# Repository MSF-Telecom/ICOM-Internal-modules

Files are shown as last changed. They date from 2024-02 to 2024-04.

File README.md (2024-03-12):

# ICOM Internal modules

A collection of custom internal modules for ICOM IC-F5060/6060 radios.

## Pinouts

The IC-F5060/6060 and IC-F3162T radios have two 40-pin accessory connectors (J1 and J2). They mate with a [Panasonic P5 Series P5K AXK640347YG](https://na.industrial.panasonic.com/products/connectors/board-board-connectors/lineup/narrow-fine-pitch-connectors/series/82696/model/83045) connector.  
You can find a KiCAD Library for J1 and J2 to make your own modules [here](./CAD-Libs/ICOM-J1-J2). The pinouts are as follows (from the service manual) :

### J1

```ascii
           ┌─────╮
      NC   │40  1│   NC
     GND   │39  2│   GND
     +5V   │38  3│   PTTI
     VCC   │37  4│   PTTO
      NC   │36  5│   MCOT
   MMUTI   │35  6│   NC
    AFON   │34  7│   MCIN
    BEPO   │33  8│   NC
    RMUT   │32  9│   NC
    DISC   │31 10│   NC
   AFOUT   │30 11│   NC
      NC   │29 12│   BUSY
     REM   │28 13│   SIGO
     CCS   │27 14│   OPT1/RxD
    CIRQ   │26 15│   OPT2/TxD
      NC   │25 16│   OPT3
     CSO   │24 17│   GND
     CSI   │23 18│   OPV3
     CCK   │22 19│   OPV2
      NC   │21 20│   OPV1
           └─────╯
```

### J2

```ascii
           ┌─────╮
     DIF   │40  1│   DIF
     GND   │39  2│   GND
     +5V   │38  3│   NC
      8V   │37  4│   NC
      NC   │36  5│   NC
      NC   │35  6│   DMO
      NC   │34  7│   NC
      NC   │33  8│   DMI
      NC   │32  9│   NC
    DISC   │31 10│   VREF
      NC   │30 11│   NC
    DAFO   │29 12│   NC
      NC   │28 13│   NC
     CCS   │27 14│   OPT1 (DPDN)
    CIRQ   │26 15│   OPT2 (DRES)
      NC   │25 16│   OPT3 (DRES)
     CSO   │24 17│   GND
     CSI   │23 18│   NC
     CCK   │22 19│   GND
     GND   │21 20│   GND
           └─────╯
```

## Acknowledgements

Made with ❤️, lots of ☕️, and lack of 🛌  
Published under CreativeCommons BY-SA 4.0

  
This work is licensed under a [Creative Commons Attribution-ShareAlike 4.0 International License](http://creativecommons.org/licenses/by-sa/4.0/).

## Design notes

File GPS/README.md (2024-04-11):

# GPS Module

All the files and R&D data for a custom GPS module.

## Module Design Specifications

A.  Must have  

  1. UT-126H form factor (20x35mm)
  2. UART NMEA GPS module with 4800/9600 baud rate
  3. 5V Supply compatible
  4. 5V Antenna supply
  5. UFL Antenna connector
  6. Test pads for VCC, GND, TX, RX and PPS

B.  Nice to have

  1. Switchable antenna supply
  2. Backup battery circuitry
  3. Antenna short circuit detection & protection

C.  Optional

  1. Antenna connection detection
  2. Additional 2.54mm pitch header with VCC, GND, UART, PPS and I2C
  3. PPS LED
  4. TX/RX LEDs

## Module Design Choices

### v1.0

#### Requirements

- PCB
  - 2 layer
  - Test pads on user visible side (satisfies A6)
  - 20x35mm form factor (satisfies A1)
  - Silk screen on user visible side with checkable baud rate options
- Connectors
  - UFL Antenna connector (satisfies A5)
  - 2.54mm pitch header with VCC, GND, UART, PPS and I2C (satisfies C2)
- Battery backup with 6.8mm SDM 3V rechargeable lithium cell (satisfies B2)
- GPS Module : [u-blox MAX-M10](https://www.u-blox.com/en/product/max-m10-series?legacy=Current#Documentation-&-resources) (can satisfy A1, A2, A3 with regulator, A4, B1, B2, B3 and C1)
- LEDs on user visible side (satisfies C3 and C4)
- No antenna short circuit detection (does not satisfy B3 or C1)
- Constant 5V antenna supply (satisfies A4, but not B1)

#### Component choice

- [u-blox MAX-M10](https://www.u-blox.com/en/product/max-m10-series?legacy=Current#Documentation-&-resources)
- Battery : [SEIKO INSTRUMENTS MS518SE-FL35E](https://www.farnell.com/datasheets/3115182.pdf) ([Farnell](https://be.farnell.com/en-BE/seiko-instruments/ms518se-fl35e/battery-button-lithium-3-4mah/dp/3534575))
- U.FL : [HIROSE(HRS) U.FL-R-SMT-1(10)](https://www.farnell.com/datasheets/2691132.pdf) ([Farnell](https://be.farnell.com/en-BE/hirose-hrs/u-fl-r-smt-1-10/rf-coaxial-u-fl-straight-jack/dp/1688077))
- C1, C2 : [0603B105K250NT](https://www.lcsc.com/datasheet/lcsc_datasheet_2304140030_FH--Guangdong-Fenghua-Advanced-Tech-0603B105K250NT_C59302.pdf)
- L1 (Antenna supply inductor, 27nH) : [Murata LQG15HS27NJ02D](https://www.mouser.be/datasheet/2/281/1/JELF243B_0010-1699614.pdf)
- C4, C5, C6 (Antenna supply filter, 10nF, 16V, X7R) : [CC0603KRX7R0BB103](https://www.lcsc.com/datasheet/lcsc_datasheet_2304140030_YAGEO-CC0603KRX7R0BB103_C107059.pdf)
- 3.3V Regulator : [SPX5205M5-L-3-3/TR](https://www.lcsc.com/datasheet/lcsc_datasheet_2304140030_MaxLinear-SPX5205M5-L-3-3-TR_C6864.pdf)
- D1 : [RB551V-40](https://www.lcsc.com/datasheet/lcsc_datasheet_2308281443_hongjiacheng-RB551V-40_C7502699.pdf)
- D2 : [KINGBRIGHT KPTR-3216SURCK](https://www.farnell.com/datasheets/2045968.pdf)
- D3 : [XL-3216SURC](https://www.lcsc.com/datasheet/lcsc_datasheet_2402181505_XINGLIGHT-XL-3216SURC_C965822.pdf)
- D4, D5 : [XL-3216UOC](https://www.lcsc.com/datasheet/lcsc_datasheet_2402181505_XINGLIGHT-XL-3216UOC_C965823.pdf)
- R1 : [ERJPA3J100V](https://www.lcsc.com/product-detail/Chip-Resistor-Surface-Mount_PANASONIC-ERJPA3J100V_C441879.html)
- R2, R3, R4 : [CR0603-FX-3301ELF](https://www.lcsc.com/datasheet/lcsc_datasheet_2304140030_BOURNS-CR0603-FX-3301ELF_C203527.pdf)
- R5, R6, R7, R8 : [RC0603JR-07220RL](https://www.lcsc.com/datasheet/lcsc_datasheet_2304140030_YAGEO-RC0603JR-07220RL_C114683.pdf)

#### Cost breakdown

> Cost for one unit at 100pcs MOQ, without PCBA

##### Full prototype with debug LEDs

| Component | Source | Cost ($) | Amount | Total ($) |
|---|---|---|---|---|
| PCB | JLCPCB | 0.141 | 1 | 0.141 |
| LQG15HS27NJ02DLQG15HS27NJ02D 27nH inductor | LCSC | 0.0065 | 1 | 0.0065 |
| U.FL-R-SMT-1(10) UFL connector | LCSC | 0.0.1177 | 1 | 0.1615 |
| SPX5205M5-L-3-3/TR 3.3V LDO regulator | LCSC | 0.1209 | 1 | 0.1209 |
| 0603B105K250NT 1uF 25V capacitor | LCSC | 0.0053 | 2 | 0.0106 |
| CC0603KRX7R0BB103 10nF 16V capacitor | LCSC | 0.0041 | 4 | 0.0164 |
| RC0603JR-07220RL 220 Ohm resistor | LCSC | 0.001 | 4 | 0.0040 |
| CR0603-FX-3301ELF 3.3k Ohm resistor | LCSC | 0.0062 | 3 | 0.0186 |
| ERJPA3J100V 10 Ohm resistor | LCSC | 0.0193 | 1 | 0.0193 |
| APTR3216SURCK Through-PCB LED | LCSC | 0.1032 | 1 | 0.1032 |
| MAX-M10S-00B GPS module | Mouser | 11.48 | 1 | 11.48 |
| AXK640347YG Connector | Mouser | 1.60 | 1 | 1.60 |
| MS518SE-FL35E Battery | Farnell| 2.15 | 1 | 2.15 |
| RB551V-40 Diode | LCSC | 0.018 | 1 | 0.018 |
| XL-3216SURC Red LED | LCSC | 0.0082 | 1 | 0.0082 |
| XL-3216UOC Orange LED | LCSC | 0.0092 | 2 | 0.0184 |
| | | | | |
| **Total** | | | | 15.8766 |

##### Integration prototype with battery backup

| Component | Source | Cost ($) | Amount | Total ($) |
|---|---|---|---|---|
| PCB | JLCPCB | 0.141 | 1 | 0.141 |
| LQG15HS27NJ02DLQG15HS27NJ02D 27nH inductor | LCSC | 0.0065 | 1 | 0.0065 |
| U.FL-R-SMT-1(10) UFL connector | LCSC | 0.0.1177 | 1 | 0.1615 |
| SPX5205M5-L-3-3/TR 3.3V LDO regulator | LCSC | 0.1209 | 1 | 0.1209 |
| 0603B105K250NT 1uF 25V capacitor | LCSC | 0.0053 | 2 | 0.0106 |
| CC0603KRX7R0BB103 10nF 16V capacitor | LCSC | 0.0041 | 4 | 0.0164 |
| RC0603JR-07220RL 220 Ohm resistor | LCSC | 0.001 | 1 | 0.0010 |
| CR0603-FX-3301ELF 3.3k Ohm resistor | LCSC | 0.0062 | 3 | 0.0186 |
| ERJPA3J100V 10 Ohm resistor | LCSC | 0.0193 | 1 | 0.0193 |
| APTR3216SURCK Through-PCB LED | LCSC | 0.1032 | 1 | 0.1032 |
| MAX-M10S-00B GPS module | Mouser | 11.48 | 1 | 11.48 |
| AXK640347YG Connector | Mouser | 1.60 | 1 | 1.60 |
| MS518SE-FL35E Battery | Farnell| 2.15 | 1 | 2.15 |
| RB551V-40 Diode | LCSC | 0.018 | 1 | 0.018 |
| | | | | |
| **Total** | | | | 15.847 |

##### Integration prototype without battery backup

| Component | Source | Cost ($) | Amount | Total ($) |
|---|---|---|---|---|
| PCB | JLCPCB | 0.141 | 1 | 0.141 |
| LQG15HS27NJ02DLQG15HS27NJ02D 27nH inductor | LCSC | 0.0065 | 1 | 0.0065 |
| U.FL-R-SMT-1(10) UFL connector | LCSC | 0.0.1177 | 1 | 0.1615 |
| SPX5205M5-L-3-3/TR 3.3V LDO regulator | LCSC | 0.1209 | 1 | 0.1209 |
| 0603B105K250NT 1uF 25V capacitor | LCSC | 0.0053 | 2 | 0.0106 |
| CC0603KRX7R0BB103 10nF 16V capacitor | LCSC | 0.0041 | 3 | 0.0164 |
| RC0603JR-07220RL 220 Ohm resistor | LCSC | 0.001 | 1 | 0.0010 |
| CR0603-FX-3301ELF 3.3k Ohm resistor | LCSC | 0.0062 | 2 | 0.0186 |
| ERJPA3J100V 10 Ohm resistor | LCSC | 0.0193 | 1 | 0.0193 |
| APTR3216SURCK Through-PCB LED | LCSC | 0.1032 | 1 | 0.1032 |
| MAX-M10S-00B GPS module | Mouser | 11.48 | 1 | 11.48 |
| AXK640347YG Connector | Mouser | 1.60 | 1 | 1.60 |
| | | | | |
| **Total** | | | | 13.6687 |

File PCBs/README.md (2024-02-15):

# PCBs

This directory contains the PCBs for the project. The PCBs are designed using KiCad.

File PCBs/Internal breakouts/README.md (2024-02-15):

# ICOM Internal Breakouts

## Why

MSF uses a lot of ICOM IC-F5000 series radios in the field. These are VHF FM radios that can be upgraded with an internal module to work as a dPMR or NXDN radios.  
We wanted to explore the capabilities of these internal expansion connectors and see if we could use them to interface with other devices (for example an FSK modulator for pagers).

In order to do some prototyping, and after trying to solder tiny wires on the tiny pads of the PCB, I decided to design a breakout board that would make it easier to interface with the radio.

After finding the correct connectors, I designed a PCB that would fit in the radio and expose the internal connectors to more standard 2.54mm pitch headers.  
The connectors for J1 and J2 are the same, but the pinout is different as J2 is intended for DSPs like the UT-126H.

I also added a connector for the internal GPS connector, as the radio can transmit GPS positions with an *external* or *internal* GPS receiver, but I've never seen the internal GPS receiver and wanted to see if it was feasable.

## BOM

* Mating connectors for J1 and J2 : [Panasonic P5 Series P5K AXK640347YG](https://na.industrial.panasonic.com/products/connectors/board-board-connectors/lineup/narrow-fine-pitch-connectors/series/82696/model/83045)
* Mating connector for 0.8mm pitch GPS connector : [Samtec FTE-105-01-G-DV](https://www.samtec.com/products/fte)
* 4x 1x10 2.54mm pitch headers
* 1x 2x5 2.54mm pitch header

## PCBs

Here are some 3D renders of the PCBs :

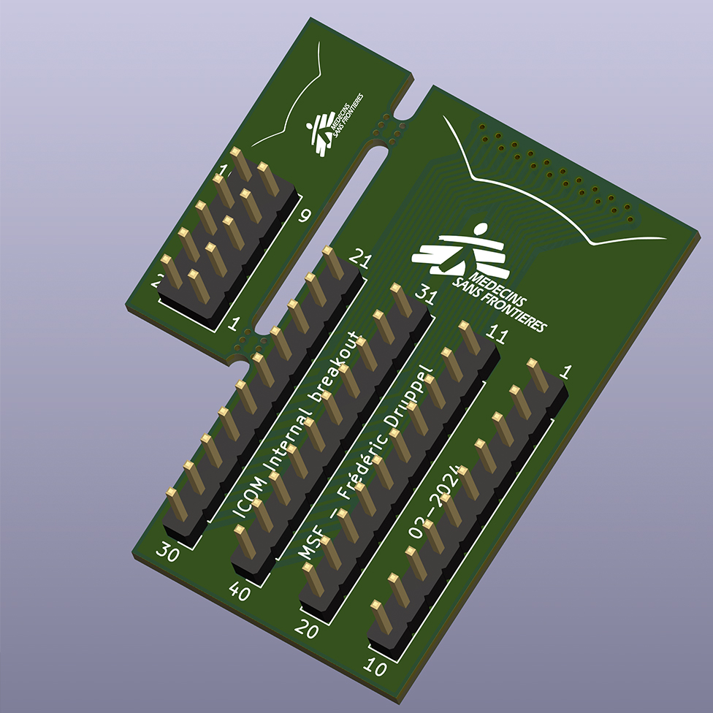
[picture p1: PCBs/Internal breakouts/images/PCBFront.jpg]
Front of PCB

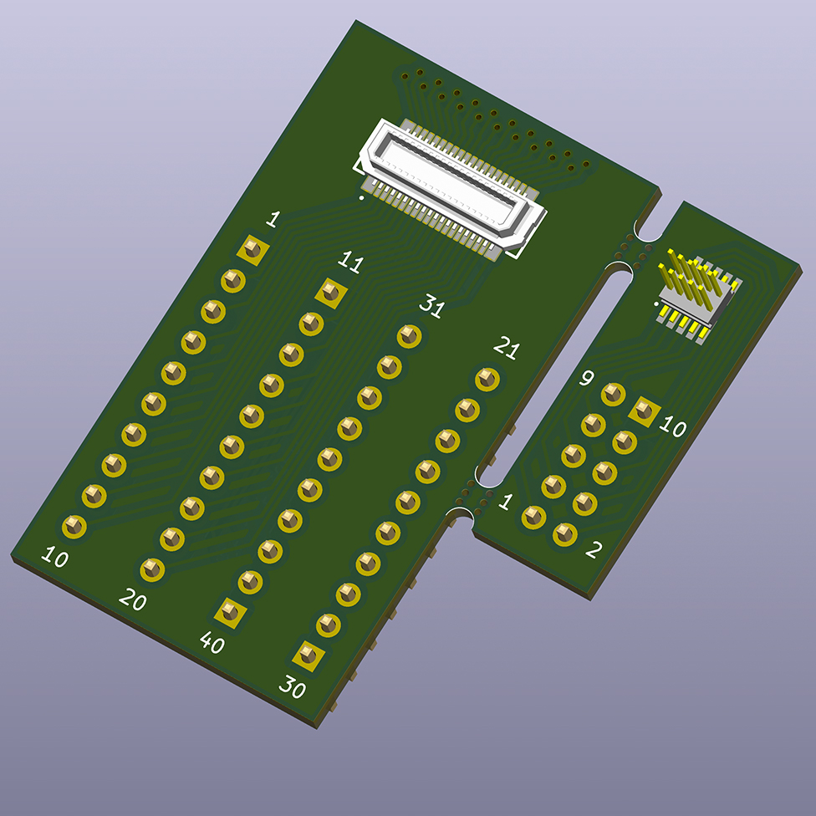
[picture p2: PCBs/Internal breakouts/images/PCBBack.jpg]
Back of PCB


> Note : Gerber files exported with default settings, you might want to re-export from KiCAD depending on your PCB manufacturer

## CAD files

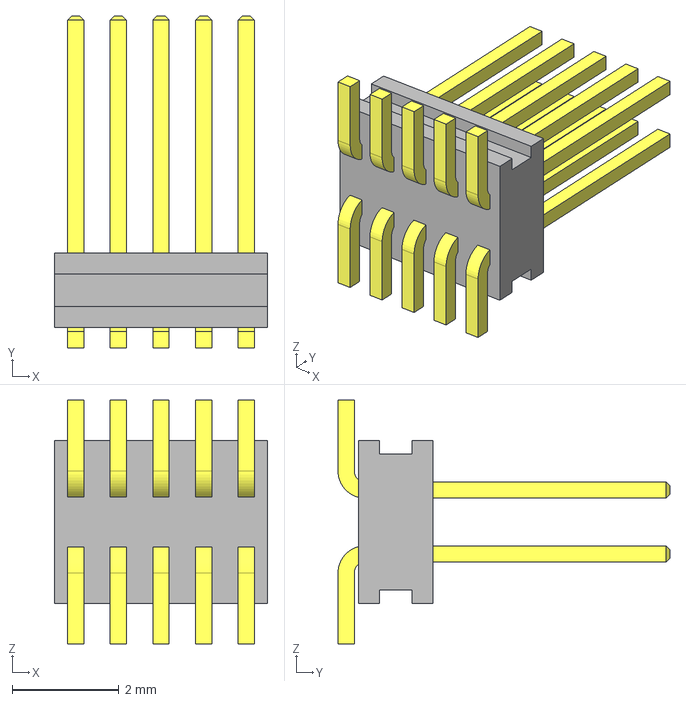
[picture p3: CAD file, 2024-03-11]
CAD-Libs/FTE-105-02-G-DV/FTE-105-02-G-DV.stp
4.00 x 6.22 x 4.57 mm
FTE-105-02-G-DV_body
FTE-105-02-G-DV_pins

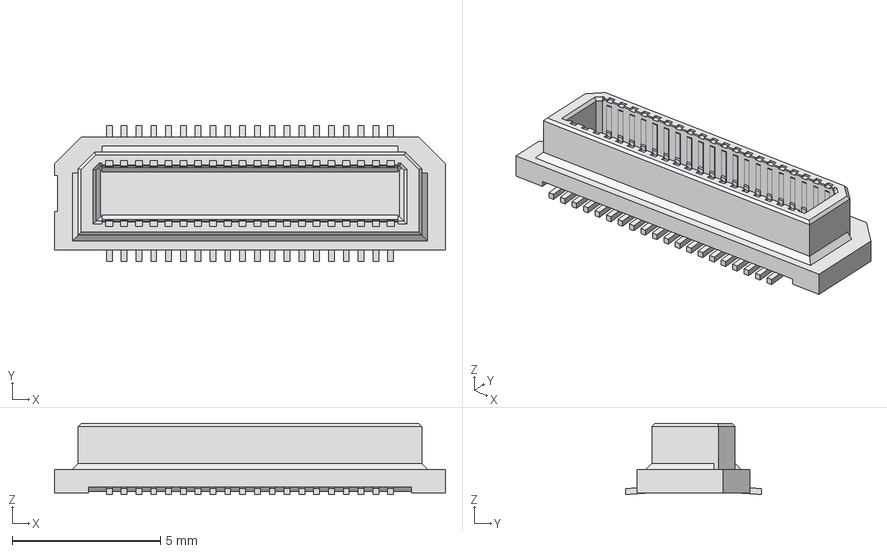
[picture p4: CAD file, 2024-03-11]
CAD-Libs/ICOM-J1-J2/ICOM-J1-J2.stp
13.2 x 4.60 x 2.40 mm

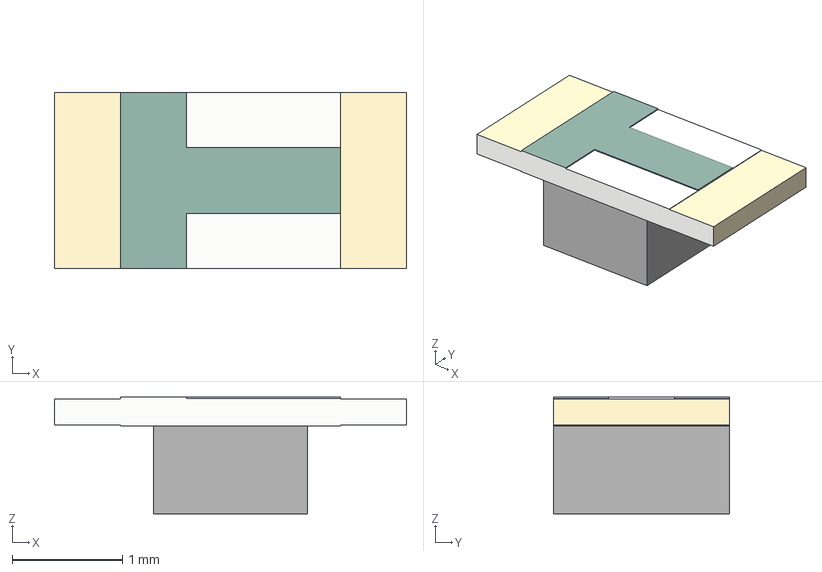
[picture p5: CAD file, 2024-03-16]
CAD-Libs/KINGBRIGHT KPTR-3216SURCK/KPTR-3216SURCK.step
3.20 x 1.60 x 1.06 mm
Base
Bulb

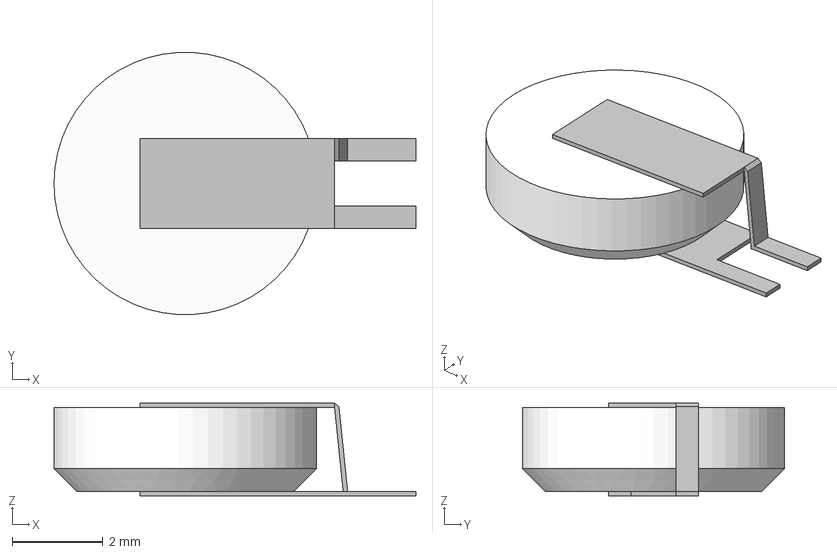
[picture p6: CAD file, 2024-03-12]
CAD-Libs/MS518SE/MS518SE FL35E.step
8.00 x 5.79 x 2.05 mm
Battery
Bottom tab
Top tab

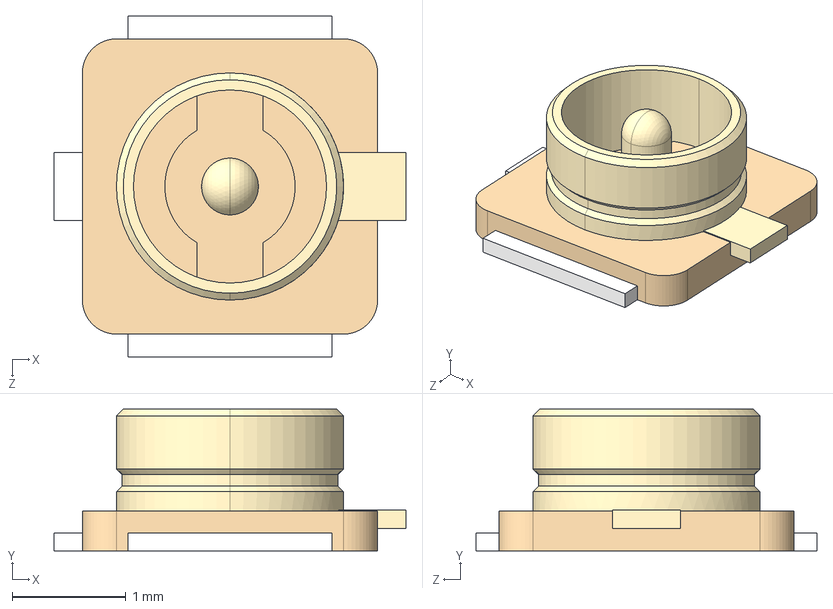
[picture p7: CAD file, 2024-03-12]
CAD-Libs/U.FL-R-SMT-1_10/U.FL-R-SMT-1_10_.step
3.10 x 1.25 x 3.00 mm

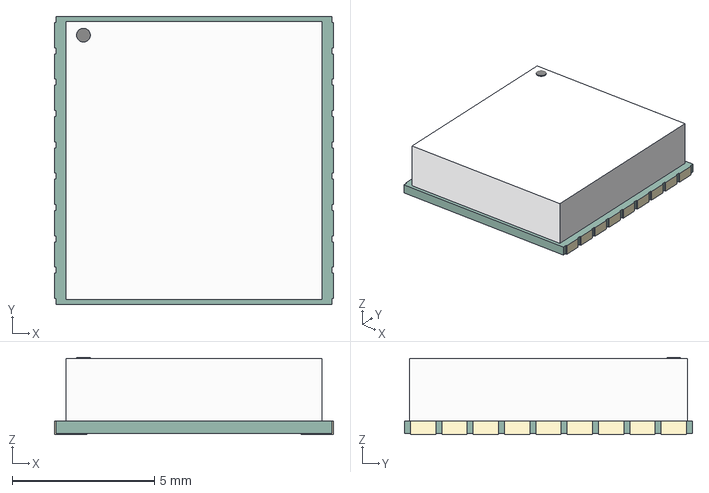
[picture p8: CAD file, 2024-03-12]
CAD-Libs/UBX-MAX-M10S/MOD18_MAX-M10M_UBL.step
9.80 x 10.1 x 2.71 mm

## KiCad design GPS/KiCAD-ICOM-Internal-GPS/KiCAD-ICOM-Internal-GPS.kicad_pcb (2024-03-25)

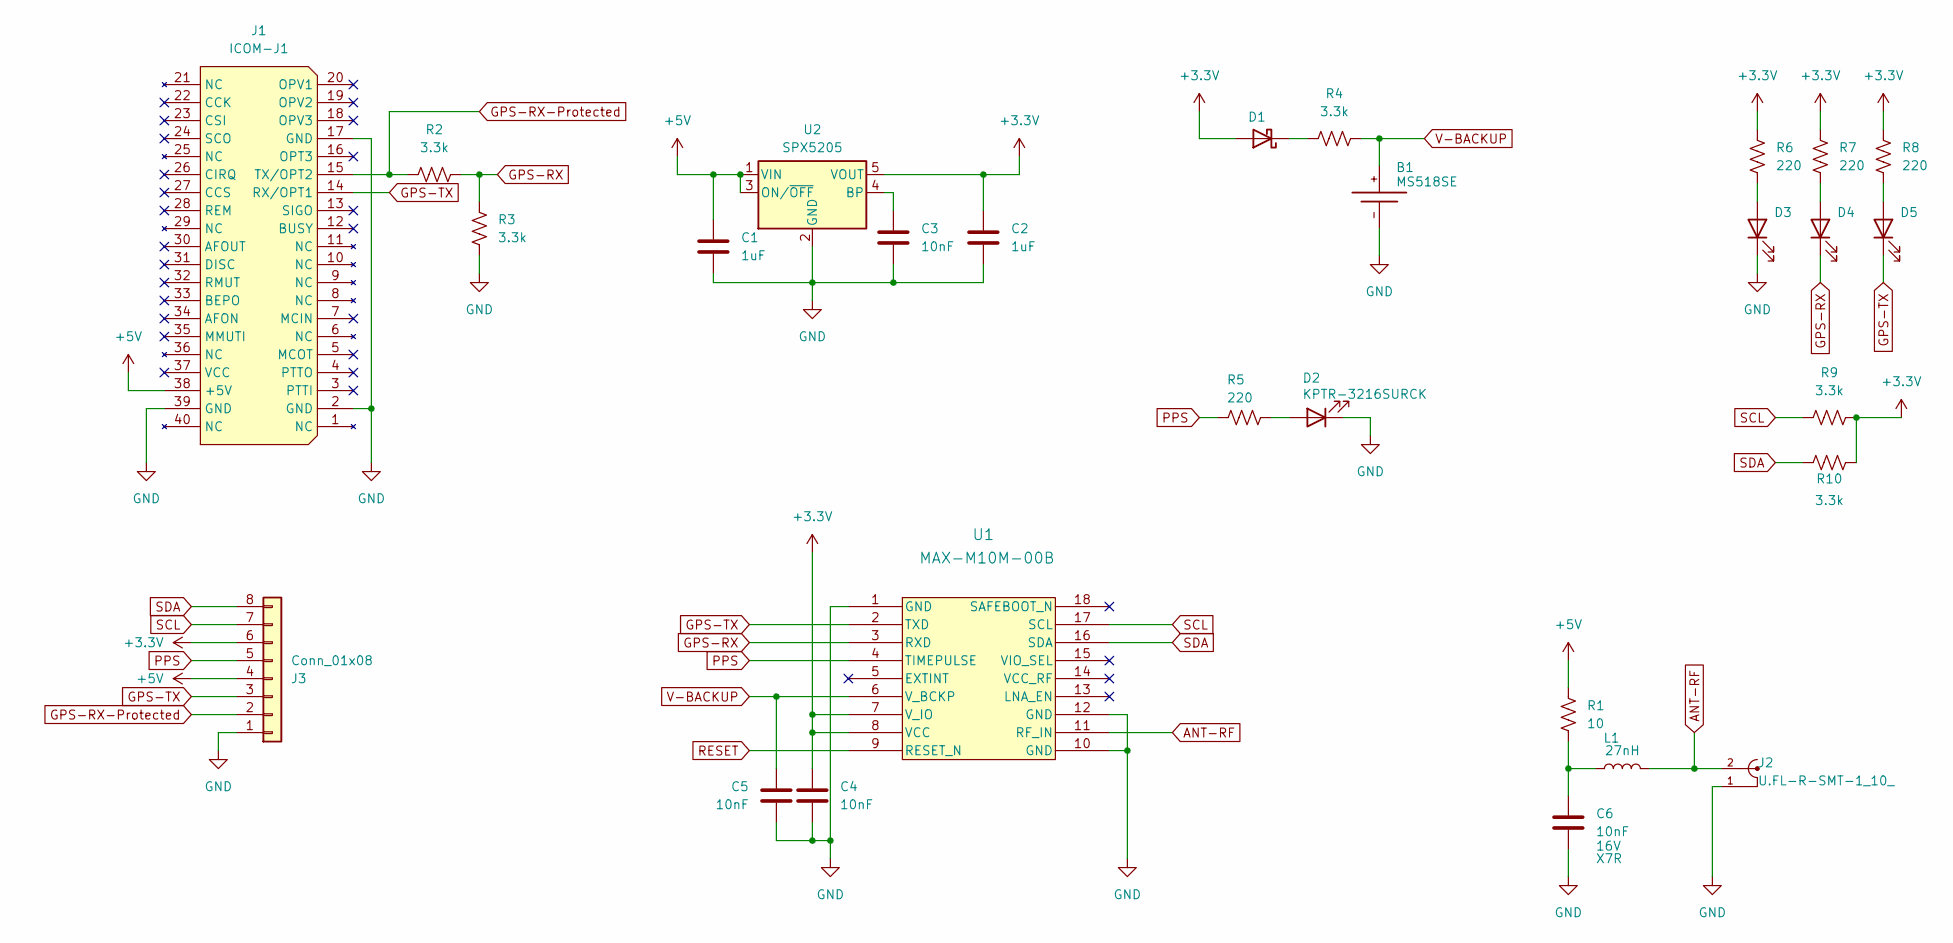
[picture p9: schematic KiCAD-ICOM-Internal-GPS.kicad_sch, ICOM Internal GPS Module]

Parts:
B1: MS518SE; MS518SE-FL35E; MPN MS518SE-FL35E; DIGIKEY 728-1054-ND
C1, C2: 1uF; C_0603_1608Metric
C3, C4, C5: 10nF; C_0603_1608Metric
C6: 10nF; C_0603_1608Metric; Voltage rating 16V
D1: RB551V-40; D_SOD-323
D2: KPTR-3216SURCK; LED320X125X130N
D3: XL-3216SURC; LED_1206_3216Metric
D4, D5: XL-3216UOC; LED_1206_3216Metric
J1: ICOM-J1; ICOM-J1-J2; Mouser Part Number 769-AXK640347YG
J2: U.FL-R-SMT-1_10_; HRS_U.FL-R-SMT-1_10_
J3: Conn_01x08; PinSocket_1x08_P2.54mm_Vertical
L1: 27nH; L_0402_1005Metric; Part number LQG15HS27NJ02D
R1: 10; R_0603_1608Metric
R2, R3, R4: 3.3k; R_0603_1608Metric
R5, R6, R7, R8: 220; R_0603_1608Metric_Pad0.98x0.95mm_HandSolder
R9, R10: 3.3k; R_0603_1608Metric_Pad0.98x0.95mm_HandSolder
U1: MAX-M10M-00B; MOD18_MAX-M10M_UBL
U2: SPX5205; SOT-23-5

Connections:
+3.3V: C2.1, C4.1, D1.2 (A), J3.6, R6.1, R7.1, R8.1, R9.2, R10.2, U1.7 (V_IO), U1.8 (VCC), U2.5 (VOUT)
+5V: C1.1, J1.38 (+5V), J3.4, R1.1, U2.1 (VIN), U2.3 (ON/~OFF)
ANT-RF: J2.2, L1.2, U1.11 (RF_IN)
GND: B1.-, C1.2, C2.2, C3.2, C4.2, C5.2, C6.2, D2.2 (K), D3.1 (K), J1.2 (GND), J1.17 (GND), J1.39 (GND), J2.1, J2.3, J3.1, R3.2, U1.1 (GND), U1.10 (GND), U1.12 (GND), U2.2 (GND)
GPS-RX: D4.1 (K), R2.2, R3.1, U1.3 (RXD)
GPS-RX-Protected: J1.15 (TX/OPT2), J3.2, R2.1
GPS-TX: D5.1 (K), J1.14 (RX/OPT1), J3.3, U1.2 (TXD)
unnamed: C6.1, L1.1, R1.2
unnamed: D1.1 (K), R4.1
unnamed: D2.1 (A), R5.2
unnamed: D3.2 (A), R6.2
unnamed: D4.2 (A), R7.2
unnamed: D5.2 (A), R8.2
unnamed: C3.1, U2.4 (BP)
PPS: J3.5, R5.1, U1.4 (TIMEPULSE)
RESET: U1.9 (RESET_N)
SCL: J3.7, R9.1, U1.17 (SCL)
SDA: J3.8, R10.1, U1.16 (SDA)
V-BACKUP: B1.+, C5.1, R4.2, U1.6 (V_BCKP)

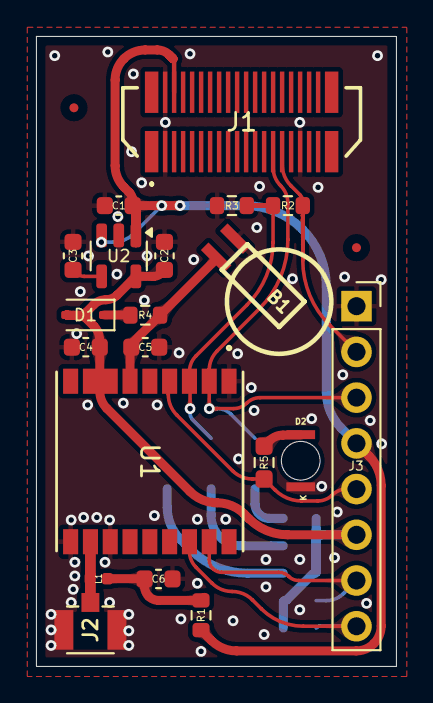
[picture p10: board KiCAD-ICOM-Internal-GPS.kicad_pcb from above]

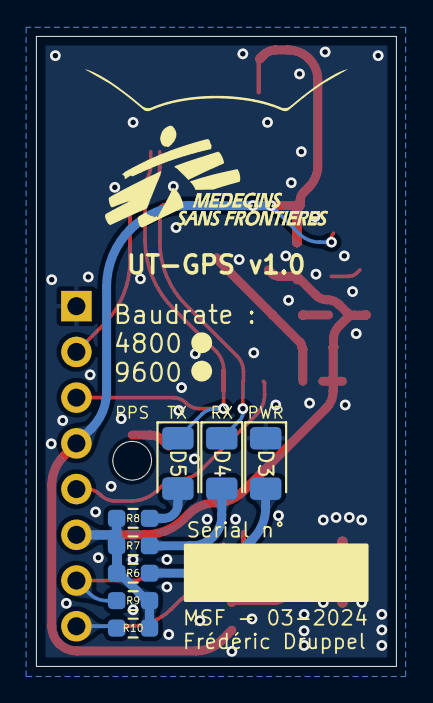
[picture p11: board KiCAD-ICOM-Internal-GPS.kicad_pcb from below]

Board: 2 copper layers, 20.0 x 35.0 mm, 30 parts (8 on the bottom side), 18 nets.

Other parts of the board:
F1, F2: Fiducial_0.5mm_Mask1.5mm

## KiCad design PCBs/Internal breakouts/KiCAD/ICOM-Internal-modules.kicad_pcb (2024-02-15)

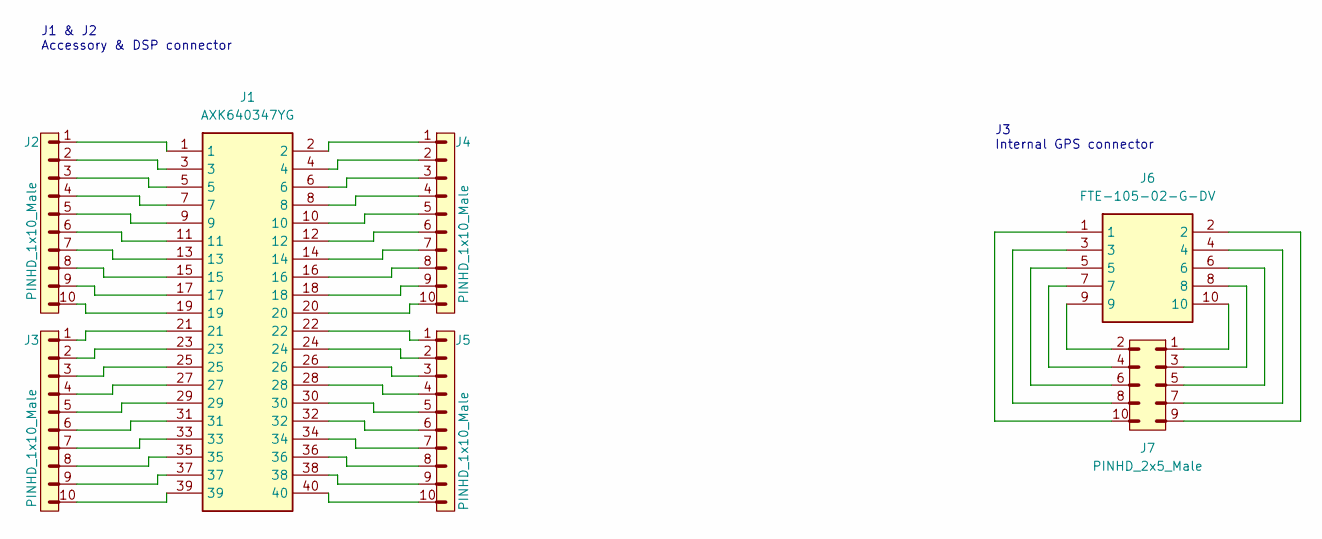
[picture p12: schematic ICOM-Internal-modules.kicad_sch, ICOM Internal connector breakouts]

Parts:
J1: AXK640347YG; Mouser Part Number 769-AXK640347YG
J2, J3, J4, J5: PINHD_1x10_Male; PinHeader_1x10_P2.54mm_Vertical
J6: FTE-105-02-G-DV; FTE-105-XX-G-DV; Mouser Part Number 200-FTE10502GDV
J7: PINHD_2x5_Male; PinHeader_2x05_P2.54mm_Vertical

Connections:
unnamed: J1.1, J2.1
unnamed: J1.2, J4.1
unnamed: J1.3, J2.2
unnamed: J1.4, J4.2
unnamed: J1.5, J2.3
unnamed: J1.6, J4.3
unnamed: J1.7, J2.4
unnamed: J1.8, J4.4
unnamed: J1.9, J2.5
unnamed: J1.10, J4.5
unnamed: J1.11, J2.6
unnamed: J1.12, J4.6
unnamed: J1.13, J2.7
unnamed: J1.14, J4.7
unnamed: J1.15, J2.8
unnamed: J1.16, J4.8
unnamed: J1.17, J2.9
unnamed: J1.18, J4.9
unnamed: J1.19, J2.10
unnamed: J1.20, J4.10
unnamed: J1.21, J3.1
unnamed: J1.22, J5.1
unnamed: J1.23, J3.2
unnamed: J1.24, J5.2
unnamed: J1.25, J3.3
unnamed: J1.26, J5.3
unnamed: J1.27, J3.4
unnamed: J1.28, J5.4
unnamed: J1.29, J3.5
unnamed: J1.30, J5.5
unnamed: J1.31, J3.6
unnamed: J1.32, J5.6
unnamed: J1.33, J3.7
unnamed: J1.34, J5.7
unnamed: J1.35, J3.8
unnamed: J1.36, J5.8
unnamed: J1.37, J3.9
unnamed: J1.38, J5.9
unnamed: J1.39, J3.10
unnamed: J1.40, J5.10
unnamed: J6.1, J7.10
unnamed: J6.2, J7.9
unnamed: J6.3, J7.8
unnamed: J6.4, J7.7
unnamed: J6.5, J7.6
unnamed: J6.6, J7.5
unnamed: J6.7, J7.4
unnamed: J6.8, J7.3
unnamed: J6.9, J7.2
unnamed: J6.10, J7.1

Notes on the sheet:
J1 & J2 Accessory & DSP connector
J3 Internal GPS connector

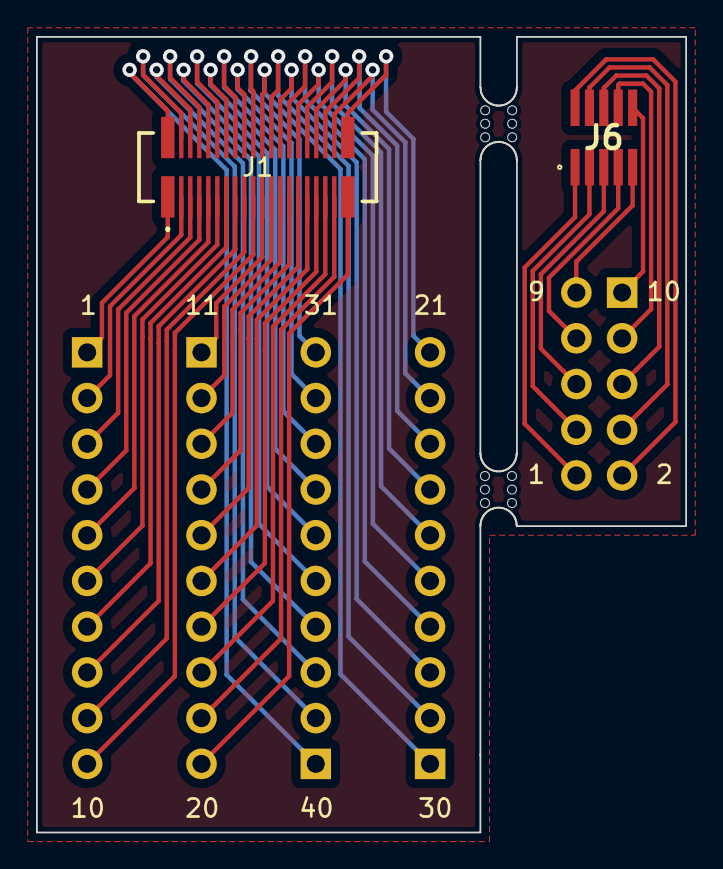
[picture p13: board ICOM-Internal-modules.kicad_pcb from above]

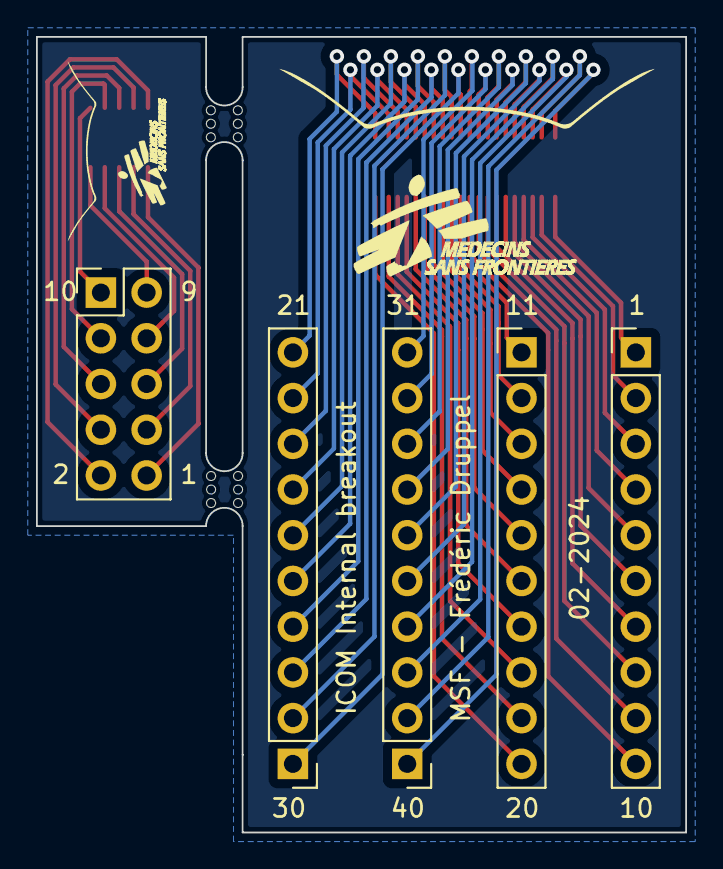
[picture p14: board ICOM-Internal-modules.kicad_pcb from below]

Board: 2 copper layers, 36.1 x 44.2 mm, 9 parts (5 on the bottom side), 50 nets.

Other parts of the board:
mouse-bite-2mm-slot, mouse-bite-2mm-slot#2: VAL**; mouse-bite-2mm-slot

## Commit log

2024-02-15 added breakout files
    [ICOM-Internal-modules-B_Cu.gbr, ICOM-Internal-modules-B_Mask.gbr, ICOM-Internal-modules-B_Paste.gbr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]
2024-02-22 added GPS data dump
    [ICOM-GPS-dump.txt]
2024-02-22 moved file
    [ICOM-GPS-dump.txt]
2024-02-22 added NEO-8M data
    [NEO8M-dump.txt]
2024-03-11 added KiCAD stuff to gitignore
2024-03-11 added base files for ICOM Internal GPS
    [KiCAD-ICOM-Internal-GPS.kicad_pcb, KiCAD-ICOM-Internal-GPS.kicad_sch]
2024-03-11 added CAD Libs for some components
    [AXK640347YG.stp, FTE-105-02-G-DV.stp]
2024-03-11 added libs
    [MOD18_MAX-M10M_UBL.step]
2024-03-11 updated KiCAD files
    [KiCAD-ICOM-Internal-GPS.kicad_pcb, KiCAD-ICOM-Internal-GPS.kicad_sch]
2024-03-11 added ICOM J1 Connector library same as AXK640347YG, except with the right pin names
    [ICOM-J1.stp]
2024-03-11 updated schematic & PCB
    [KiCAD-ICOM-Internal-GPS.kicad_pcb, KiCAD-ICOM-Internal-GPS.kicad_sch]
2024-03-12 updated ICOM J1/J2 library
    [ICOM-J1-J2.stp]
2024-03-12 updated schematic a bit
    [KiCAD-ICOM-Internal-GPS.kicad_pcb, KiCAD-ICOM-Internal-GPS.kicad_sch]
2024-03-12 Update accessory connector information in README.md
2024-03-12 updated libs
    [MS518SE FL35E.step, U.FL-R-SMT-1_10_.step]
2024-03-12 updated v1.0 design
    [KiCAD-ICOM-Internal-GPS.kicad_pcb, KiCAD-ICOM-Internal-GPS.kicad_sch]
2024-03-12 updated MAX-M10 3D model
    [MOD18_MAX-M10M_UBL.step]
2024-03-12 minor save
    [KiCAD-ICOM-Internal-GPS.kicad_pcb]
2024-03-15 updated schematic and pcb
    [KiCAD-ICOM-Internal-GPS.kicad_pcb, KiCAD-ICOM-Internal-GPS.kicad_sch]
2024-03-16 added LED CAD lib
    [KPTR-3216SURCK.step]
2024-03-16 Routed traces
    [KiCAD-ICOM-Internal-GPS.kicad_pcb, KiCAD-ICOM-Internal-GPS.kicad_sch]
2024-03-24 saved changes from KiCAD
    [KiCAD-ICOM-Internal-GPS.kicad_pcb, KiCAD-ICOM-Internal-GPS.kicad_sch]
2024-03-25 Add GPS schematics, gerber files, and component information
    [KiCAD-ICOM-Internal-GPS.kicad_pcb]
2024-04-11 added PCB to cost

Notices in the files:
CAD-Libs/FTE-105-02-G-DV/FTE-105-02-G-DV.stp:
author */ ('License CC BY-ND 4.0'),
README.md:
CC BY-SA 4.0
